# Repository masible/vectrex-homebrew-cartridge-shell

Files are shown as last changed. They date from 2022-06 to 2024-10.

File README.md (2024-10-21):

# Vectrex Homebrew Cartridge Shell

Remix of [Vectrex Cartridge Case](https://www.printables.com/model/125566-vectrex-cartridge-case)
modified to better accommodate RetroElectronik homebrew cartridge PCBs
and WireOut-RE.

The original version of the bottom shell did not fit my copy of
[Wireout-RE](http://www.futurevector.eu/Wireout-re.html) at all (PCB too long,
and pegs too big), or the r2tronik test cartridge.

## License

Originally available as [Vectrex Cartridge Case](https://www.printables.com/model/125566-vectrex-cartridge-case) by [InsaneDruid](https://www.printables.com/social/19592-insanedruid), licensed under [CC-BY 4.0](http://creativecommons.org/licenses/by/4.0/).

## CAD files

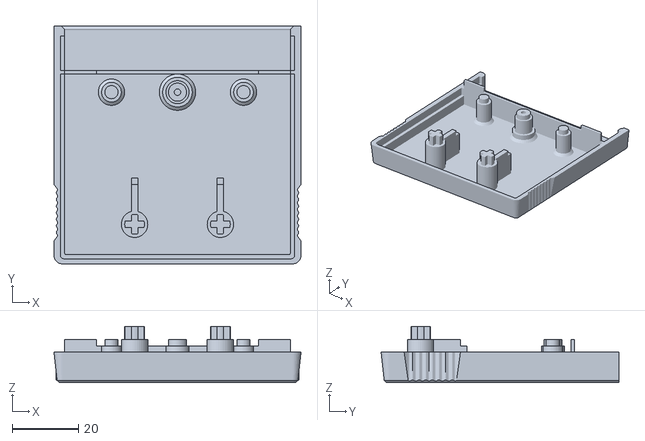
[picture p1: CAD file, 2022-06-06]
original/vectrex_cartridge_bottom.stl
74.8 x 72.0 x 17.0

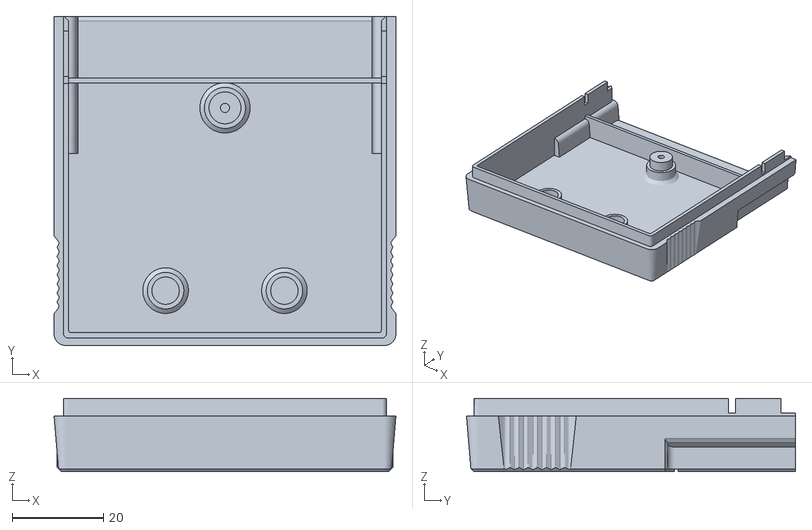
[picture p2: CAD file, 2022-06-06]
original/vectrex_cartdridge_top.stl
74.8 x 72.0 x 16.0

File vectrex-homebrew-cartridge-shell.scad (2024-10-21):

$fn = 100;

diameter_center_peg_top = 5.4;

// Single small side peg
module vectrex_small_peg_fix(top_peg_d, with_support) {
    union() {
        color("Red")
        cylinder(h = 9, d = 6.0);

        color("Green")
        translate([0, 0, 9])
        cylinder(h = 2, d = top_peg_d);

        color("Blue")
        cylinder(h = 3, d1 = 8, d2 = 4);
        if (with_support != 0) {
            color("Purple")
            translate([-1.5, 0, 0])
            cube([3, 5.5, 9]);
        }
    }
}

// Remove the small pegs
module shell_no_pegs() {
    difference() {
        color("Gold")
        import("original/vectrex_cartridge_bottom.stl", convexity=10);

        translate([-24, 12, 2])
        cube([8, 8, 12]);
        
        translate([16, 12, 2])
        cube([8, 8, 12]);
    }
}

// Remove the smaller pegs and the top of the bigger one
module shell_middle_peg() {
    difference() {
        shell_no_pegs();
        
        color("Brown")
        translate([-6, 12, 11])
        cube([12, 8, 2.01]);
    }
}

// Remove the top bracket for longer PCBs
module shell_no_top_bracket(top_peg_d) {
    difference() {
        union() {
            shell_middle_peg();
            
            difference() {
                translate([0, 16, 11])
                cylinder(h = 2, d = top_peg_d);

                translate([0, 16, -1])
                cylinder(h = 15, d = 2);
            }
        }
        
        translate([8.6, -30, 11])
        cube([9, 18.1, 6.1]);
        
        translate([-17.6, -30, 11])
        cube([9, 18.1, 6.1]);
    }
}

module shell_wireout_variant() {
    union () {
        shell_no_top_bracket(5.1);

        translate([-(15.96 + 3.85/2 + 5.1/2), 16, 2])
        vectrex_small_peg_fix(3.7, 1);
        
        translate([15.96 + 3.85/2 + 5.1/2, 16, 2])
        vectrex_small_peg_fix(3.7, 1);
    }
}

module shell_retroelectronik_variant() {
    union () {
        shell_no_pegs();

        diameter_side_hole = 3.95;
        diameter_side_peg = 3.9;

        // Right
        translate([-(14.85 + diameter_side_hole/2 + diameter_center_peg_top/2), 16, 2])
        vectrex_small_peg_fix(diameter_side_peg, 1);
        
        //Left
        //edge to edge 15.2,
        translate([15.2 + diameter_side_hole/2 + diameter_center_peg_top/2, 16, 2])
        vectrex_small_peg_fix(diameter_side_peg, 1);
    }
}

module shell_top_wireout_variant() {
    union() {
        color("Gold")
        import("original/vectrex_cartdridge_top.stl", convexity=10);

        diameter_peg = 3.3;
        translate([0, 16 - diameter_peg - 1.5 - 25.6, 0])
        vectrex_small_peg_fix(diameter_peg, 0);
    }
}

module shell_top_retroelectronik_variant() {
    color("Gold")
    import("original/vectrex_cartdridge_top.stl", convexity=10);
}

//vectrex_small_peg_fix(3.75);
//vectrex_small_peg_fix(4);
//vectrex_small_peg_fix(3.6);
//shell_no_pegs();
//shell_no_top_bracket();

//shell_wireout_variant();
//shell_retroelectronik_variant();

shell_top_wireout_variant();
shell_top_retroelectronik_variant();

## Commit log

2022-06-06 vectrex-cartridge-shell-updated
    Original files from https://www.printables.com/model/125566-vectrex-cartridge-case
    [vectrex_cartdridge_top.stl, vectrex_cartridge_bottom.stl]
2022-06-06 Add modified model sources
    [vectrex-cartridge-shell-updated.scad, vectrex_cartridge_bottom.stl]
2022-06-06 Add Makefile to generate STL files
2022-06-06 Fix preview errors
    [vectrex-cartridge-shell-updated.scad]
2022-06-12 another go
    [vectrex-cartridge-shell-updated.scad]
2024-09-05 Make Test cart work
    [vectrex-cartridge-shell-updated.scad]
2024-10-21 All fixed now!
    [vectrex-cartridge-shell-updated.scad]
2024-10-21 Rename and reorder targets
    [vectrex-cartridge-shell-updated.scad]
2024-10-21 Move original top shell
    [vectrex-cartridge-shell-updated.scad, vectrex_cartdridge_top.stl]
2024-10-21 Generate top case for Retroelectronik variant
    [vectrex-cartridge-shell-updated.scad]
2024-10-21 Rename scad file
    [vectrex-homebrew-cartridge-shell.scad]
